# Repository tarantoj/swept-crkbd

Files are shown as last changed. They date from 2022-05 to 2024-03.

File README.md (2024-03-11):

# Swept Corne
## This board designed is now stable and has reached maintenance mode.

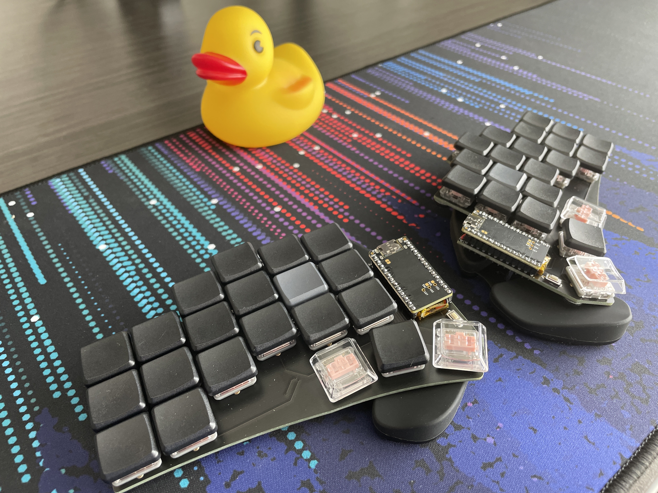
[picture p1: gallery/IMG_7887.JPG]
front of a built swept


back of a built swept

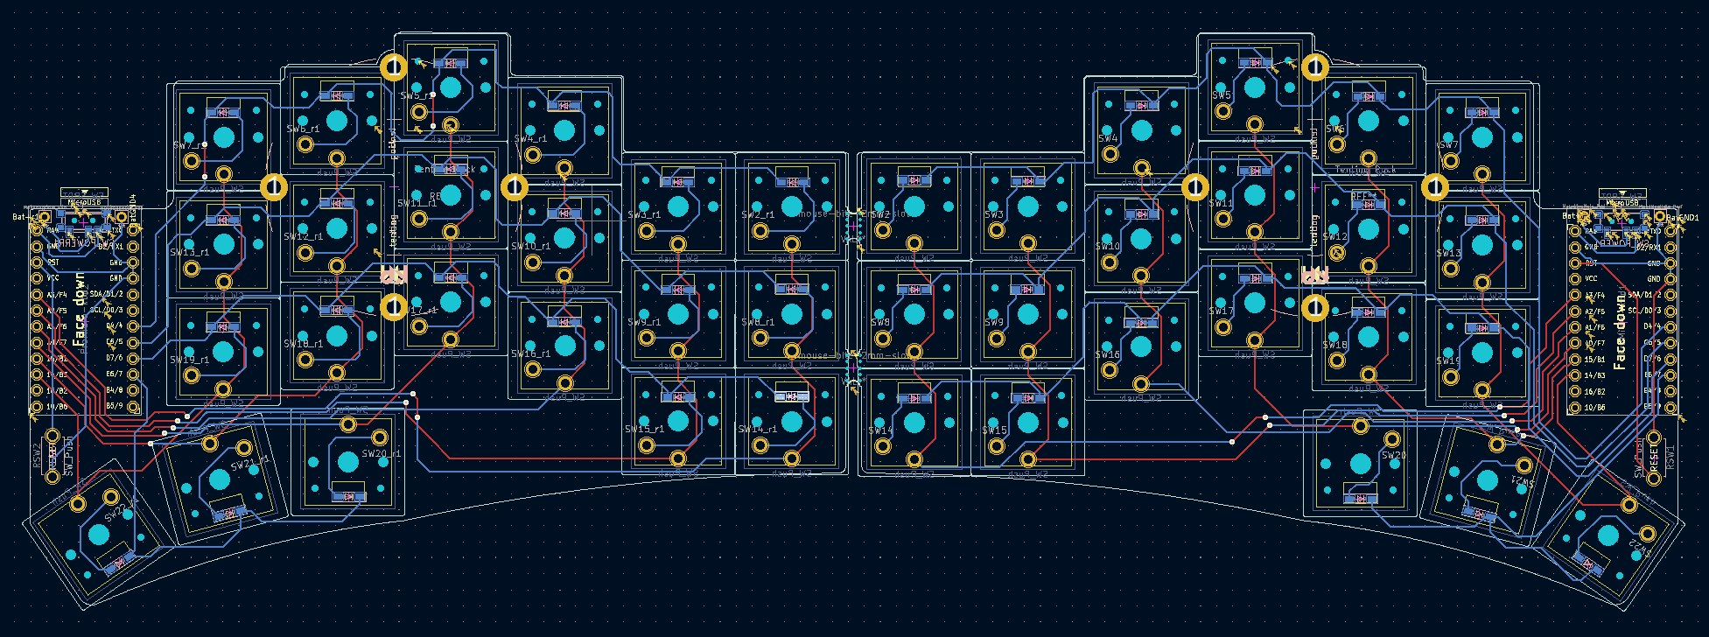
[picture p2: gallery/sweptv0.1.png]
swept v0.1 pcb


## What is the swept corne?

The Swept Corne is a mix between the [Sweep](https://github.com/davidphilipbarr/Sweep) (which is itself a version of the [Ferris](https://github.com/pierrechevalier83/ferris)) and the [Corne](https://github.com/foostan/crkbd).

## Motivation

I made the jump from a 60% qwerty keyboard to colemak mod-dh on a sweep. After getting up to speed both with the new layout and form factor I realized that to reach peak productivity I'd need a few more keys and the corne was the obvious choice but the non-choc spacing,
lack support for a power switch and the less aggresive staggering made me miss the sweep, so I decided to take the sweep as a starting point and add the extra keys by keeping it wireless friendly. The [Corne-is Zen](https://lowprokb.ca/products/corne-ish-zen) has similar
goals but up to this point has only been available through group buys and is closed source.

## What are the different types?

There's currently only one version of the swept with choc spacing as well as an on-off switch and no TRRS connector, this is to have the reset switch in a more comfortable position.

## Components list

To build and use a Swept you will need

* 1x PCB Kit (Instructions on how to order below).
* 2 nice!nanos. [Typeractive](https://typeractive.xyz/) has good prices, as well as fast shipping and processing.
* 2 batteries. From [Typeractive](https://typeractive.xyz/products/lithium-battery-110mah).
* 2 Mill-Max sockets with pins. Make sure you get the high-profile ones, low-profile still fits a battery underneath but there's less space. [Typeractive](https://typeractive.xyz/products/machine-sockets-and-pins) carries the correct size.
* 42 Choc v1 switches. You can get them from [MKUltra](https://mkultra.click/choc-switches).
* 84 Mill-Max 3305 or 7305 sockets, you can get either model from [prevailkey](https://prevailkeyco.com/products/3305-mill-max-sockets?variant=42568596193534). These are optional but you can use them to make your board hot-swap. I recommend getting some extra ones because they're very easy to lose.
* 42 smd diodes. From [MKUltra](https://mkultra.click/diode-1n4148-sod-123f/) for flush SOD-123F form factor, or from [Boardsource](https://boardsource.xyz/store/5ec9fc5d64caf04f83aa646c) for glass smd form factor; the former ones might be easier to solder for some people. I recommend getting some extra ones because they're very easy to lose.
* 42 keycaps. You can get them from [MKUltra](https://mkultra.click/mbk-choc-keycaps) or [Boardsource](https://boardsource.xyz/store/5f6ef2d68e3bf05ab838f918). I recommend getting a least a couple of homing keys, available from both providers.
* 2x reset switches ([B3U-1000P(M)](https://github.com/davidphilipbarr/Sweep/issues/20)). [This kit](https://www.amazon.com/dp/B07LCBLB8N?psc=1&ref=ppx_yo2ov_dt_b_product_details) includes switches that fit.
* Rubber feet, [these](https://www.amazon.com/dp/B07CNQC695?psc=1&ref=ppx_yo2ov_dt_b_product_details) work great.
* 2x power switches. [these](https://www.amazon.com/Gikfun-Switch-Toggle-Arduino-AE1073/dp/B01GFFGA4I/ref=psdc_495324_t1_B07SJWWYZP) work great.
* 1 USB C cable.

Note: All purchase links are for the US, PRs with links for other countries are welcome.

## Ordering The PCB

To order the PCB the following settings are recommended: 

|Detail|Value|
|---|---|
|Gerber file|`Swept_Y_vX.zip` where Y stands for variation and X stands for version|
|Base material|FR-4|
|Layers|2|
|Dimension| Depends on the board, this is picked up automatically by JLCPCB|
|Different design|2|
|Delivery format|Panel by customer|
|PCB thickness|1.6mm|
|PCB color|(Personal preference)|
|Silkscreen|(Personal preference)|
|Surface finish|(Personal preference)|
|Outer copper weight|1oz|
|Gold Fingers|No|
|Confirm production file|No|
|Castellated holes|No|
|Remove order number|Yes|

Find the different versions on the releases page.

1: Settings are for [JLCPCB](https://jlcpcb.com/), but could work for other manufacturers.

2: Settings are taken from [Kyek's video guide](https://www.youtube.com/watch?v=fBPu7AyDtkM&t=17s).

## How do I make this thing?

Build video coming soon.

## What if I want one but I don't want to build it?

Visit [my Etsy shop](https://www.etsy.com/listing/1235225784/custom-swept-corne-split-wireless) to get one built by me.

## Firmware

Firmware for zmk and nice!nano is called ["Corne"](https://zmk.dev/docs/hardware/).

[My personal configuration](https://github.com/AYM1607/corne-zmk-config). Tested on the v0.1 version.

## Changelog

### v1.1.1 (Recommended version)

- Added extra mountig holes for ease of case design.

### v1.1.0 

- Added support for the [nice!view](https://nicekeyboards.com/nice-view) sharp memory displays. You don't need it to build a keyboard, it's completely optional.

### v1.0.0 

- Boards now have optional support for Kailh choc hot-swap sockets.
- The form factor is not exactly the same to accomodate the sockets.

### v0.2.0

- Introduced the Swept Corne 3x5
- All the diodes now face the same way on both boards.

### v0.1.2 

- Updated silk screen to make the battery polarity easier to read.

### v0.1.1

- Deleted extra holes from the switch footprint which might be causing manufacturers to charge extra.

### v0.1

Differences from the original Sweep:
- Added an extra pinky column.
- Added an extra thumb key.
- Converted from direct to switch connections to matrix with diodes keeping compatibility with the corne.

The following versioning schema will be followed as closely as possible.
- Major versions: Changes to the form factor.
- Minor versions: Changes that affect the build processs, e.g. Position or orientation of components.
- Patch versions: No change to the build process.

## Who made this?

* [AYM1607](https://github.com/AYM1607)

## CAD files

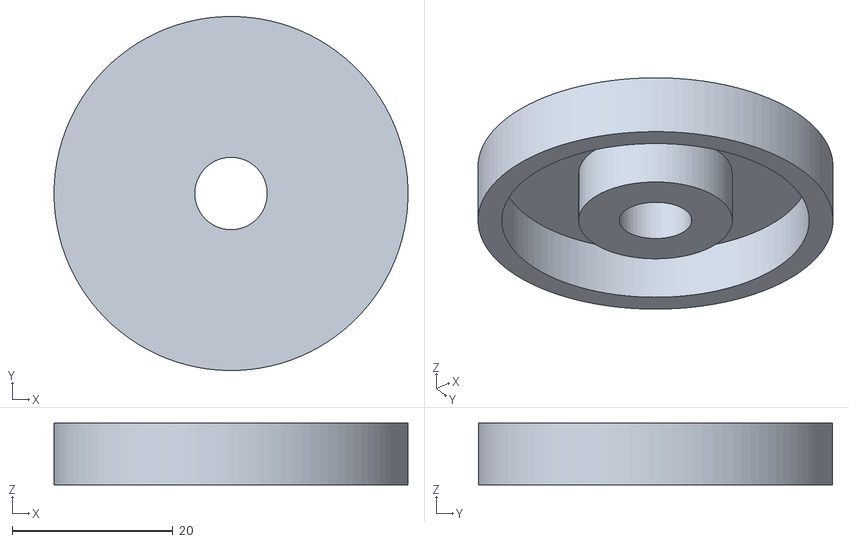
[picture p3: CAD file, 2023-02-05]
cases/Puck.stl
44.0 x 44.0 x 7.70

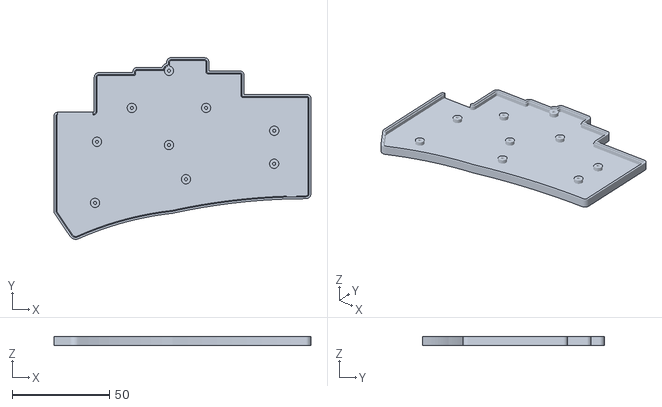
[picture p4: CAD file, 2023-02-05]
cases/v1.1.1/3x6_right_slim.stl
131.8 x 93.2 x 4.50

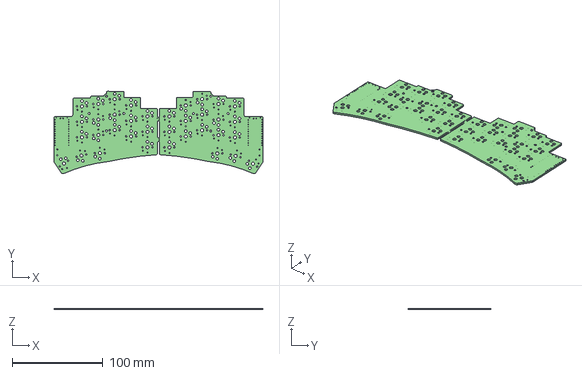
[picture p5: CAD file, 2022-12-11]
Swept_3x5/Swept_3x5.step
229.8 x 90.7 x 1.60 mm

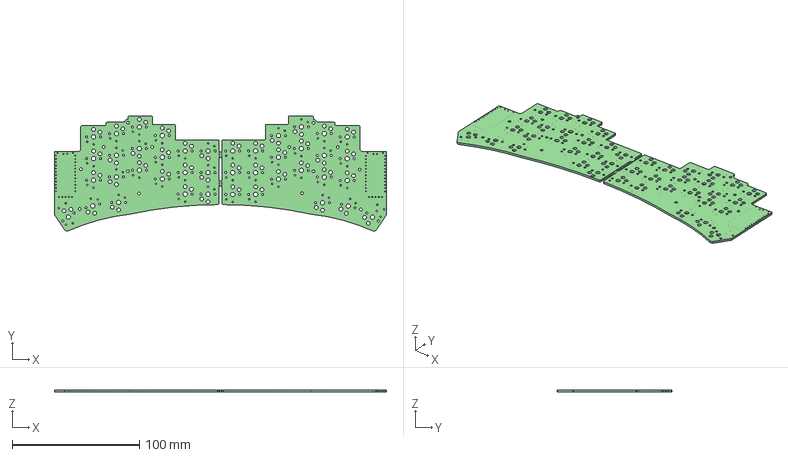
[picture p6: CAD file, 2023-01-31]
Swept_3x6/Swept_3x6.step
261.1 x 90.7 x 1.60 mm

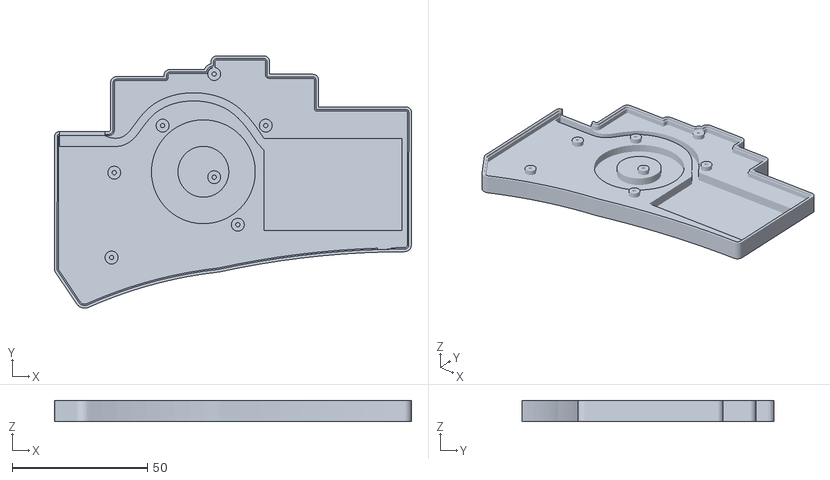
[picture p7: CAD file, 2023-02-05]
cases/v1.1.1/3x6_right.stl
131.8 x 93.2 x 7.80

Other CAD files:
cases/v1.1.1/3x6_left_slim.stl
cases/v1.1.1/3x6_left.stl
cases/v1.0.0/3x6_left.stl
cases/v1.1.0/3x6_left.stl
cases/v1.1.0/3x6_left_slim.stl
cases/v1.0.0/3x6_left_slim.stl

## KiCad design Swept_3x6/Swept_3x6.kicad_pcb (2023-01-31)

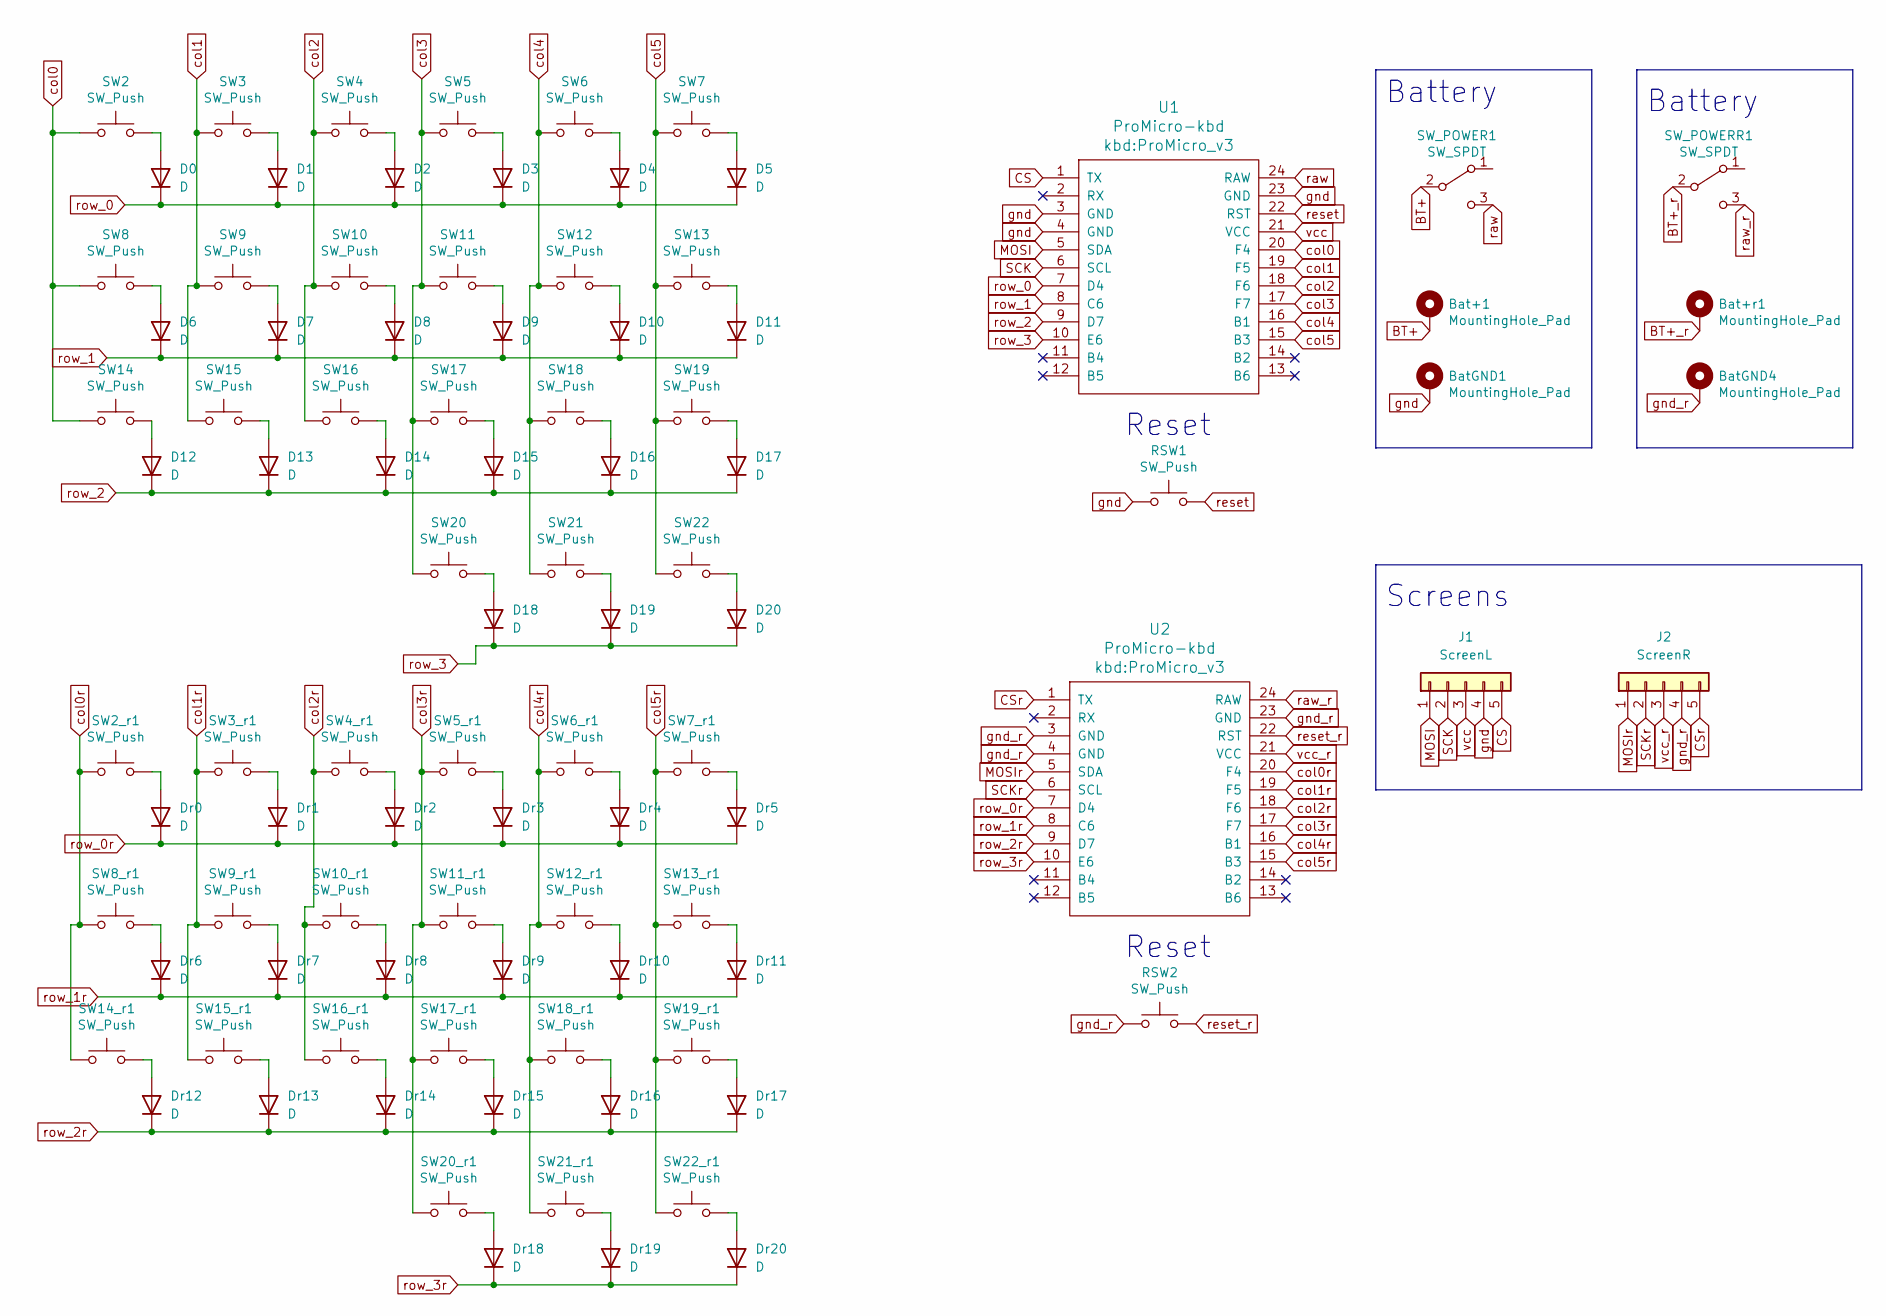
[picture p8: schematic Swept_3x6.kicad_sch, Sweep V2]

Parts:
Bat+1: MountingHole_Pad; 1pin_conn
Bat+r1: MountingHole_Pad; 1pin_conn
BatGND1, BatGND4: MountingHole_Pad; 1pin_conn
D0, D1, D2, D3, D4, D5, D6, D7, D8, D9, D10, D11, D12, D13, D14, D15, D16, D17, D18, D19, D20: D; D3_SMD_v2; LCSC C2099
Dr0, Dr1, Dr2, Dr3, Dr4, Dr5, Dr6, Dr7, Dr8, Dr9, Dr10, Dr11, Dr12, Dr13, Dr14, Dr15, Dr16, Dr17, Dr18, Dr19, Dr20: D; D3_SMD_v2; LCSC C2099
J1: ScreenL; PinHeader_1x05_P2.54mm_Vertical
J2: ScreenR; PinHeader_1x05_P2.54mm_Vertical
RSW1, RSW2: SW_Push; ResetSW
SW2, SW2_r1, SW3, SW3_r1, SW4, SW4_r1, SW5, SW5_r1, SW6, SW6_r1, SW7, SW7_r1, SW8, SW8_r1, SW9, SW9_r1, SW10, SW10_r1, SW11, SW11_r1, SW12, SW12_r1, SW13, SW13_r1, SW14, SW14_r1, SW15, SW15_r1, SW16, SW16_r1, SW17, SW17_r1, SW18, SW18_r1, SW19, SW19_r1, SW20, SW20_r1, SW21, SW21_r1, SW22, SW22_r1: SW_Push; Kailh_socket_PG1350_optional
SW_POWER1: SW_SPDT; SW_SPDT_PCM12
SW_POWERR1: SW_SPDT; SW_SPDT_PCM12
U1, U2: ProMicro-kbd; ProMicro_v3

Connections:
BT+: Bat+1.1, SW_POWER1.2 (B)
BT+_r: Bat+r1.1, SW_POWERR1.2 (B)
CS: J1.5, U1.1 (TX)
CSr: J2.5, U2.1 (TX)
MOSI: J1.1, U1.5 (SDA)
MOSIr: J2.1, U2.5 (SDA)
unnamed: D0.2 (A), SW2.2
unnamed: D1.2 (A), SW3.2
unnamed: D2.2 (A), SW4.2
unnamed: D3.2 (A), SW5.2
unnamed: D4.2 (A), SW6.2
unnamed: D5.2 (A), SW7.2
unnamed: D6.2 (A), SW8.2
unnamed: D7.2 (A), SW9.2
unnamed: D8.2 (A), SW10.2
unnamed: D9.2 (A), SW11.2
unnamed: D10.2 (A), SW12.2
unnamed: D11.2 (A), SW13.2
unnamed: D12.2 (A), SW14.2
unnamed: D13.2 (A), SW15.2
unnamed: D14.2 (A), SW16.2
unnamed: D15.2 (A), SW17.2
unnamed: D16.2 (A), SW18.2
unnamed: D17.2 (A), SW19.2
unnamed: D18.2 (A), SW20.2
unnamed: D19.2 (A), SW21.2
unnamed: D20.2 (A), SW22.2
unnamed: Dr0.2 (A), SW2_r1.2
unnamed: Dr1.2 (A), SW3_r1.2
unnamed: Dr2.2 (A), SW4_r1.2
unnamed: Dr3.2 (A), SW5_r1.2
unnamed: Dr4.2 (A), SW6_r1.2
unnamed: Dr5.2 (A), SW7_r1.2
unnamed: Dr6.2 (A), SW8_r1.2
unnamed: Dr7.2 (A), SW9_r1.2
unnamed: Dr8.2 (A), SW10_r1.2
unnamed: Dr9.2 (A), SW11_r1.2
unnamed: Dr10.2 (A), SW12_r1.2
unnamed: Dr11.2 (A), SW13_r1.2
unnamed: Dr12.2 (A), SW14_r1.2
unnamed: Dr13.2 (A), SW15_r1.2
unnamed: Dr14.2 (A), SW16_r1.2
unnamed: Dr15.2 (A), SW17_r1.2
unnamed: Dr16.2 (A), SW18_r1.2
unnamed: Dr17.2 (A), SW19_r1.2
unnamed: Dr18.2 (A), SW20_r1.2
unnamed: Dr19.2 (A), SW21_r1.2
unnamed: Dr20.2 (A), SW22_r1.2
SCK: J1.2, U1.6 (SCL)
SCKr: J2.2, U2.6 (SCL)
col0: SW2.1, SW8.1, SW14.1, U1.20 (F4)
col0r: SW2_r1.1, SW8_r1.1, SW14_r1.1, U2.20 (F4)
col1: SW3.1, SW9.1, SW15.1, U1.19 (F5)
col1r: SW3_r1.1, SW9_r1.1, SW15_r1.1, U2.19 (F5)
col2: SW4.1, SW10.1, SW16.1, U1.18 (F6)
col2r: SW4_r1.1, SW10_r1.1, SW16_r1.1, U2.18 (F6)
col3: SW5.1, SW11.1, SW17.1, SW20.1, U1.17 (F7)
col3r: SW5_r1.1, SW11_r1.1, SW17_r1.1, SW20_r1.1, U2.17 (F7)
col4: SW6.1, SW12.1, SW18.1, SW21.1, U1.16 (B1)
col4r: SW6_r1.1, SW12_r1.1, SW18_r1.1, SW21_r1.1, U2.16 (B1)
col5: SW7.1, SW13.1, SW19.1, SW22.1, U1.15 (B3)
col5r: SW7_r1.1, SW13_r1.1, SW19_r1.1, SW22_r1.1, U2.15 (B3)
gnd: BatGND1.1, J1.4, RSW1.1, U1.3 (GND), U1.4 (GND), U1.23 (GND)
gnd_r: BatGND4.1, J2.4, RSW2.1, U2.3 (GND), U2.4 (GND), U2.23 (GND)
raw: SW_POWER1.3 (C), U1.24 (RAW)
raw_r: SW_POWERR1.3 (C), U2.24 (RAW)
reset: RSW1.2, U1.22 (RST)
reset_r: RSW2.2, U2.22 (RST)
row_0: D0.1 (K), D1.1 (K), D2.1 (K), D3.1 (K), D4.1 (K), D5.1 (K), U1.7 (D4)
row_0r: Dr0.1 (K), Dr1.1 (K), Dr2.1 (K), Dr3.1 (K), Dr4.1 (K), Dr5.1 (K), U2.7 (D4)
row_1: D6.1 (K), D7.1 (K), D8.1 (K), D9.1 (K), D10.1 (K), D11.1 (K), U1.8 (C6)
row_1r: Dr6.1 (K), Dr7.1 (K), Dr8.1 (K), Dr9.1 (K), Dr10.1 (K), Dr11.1 (K), U2.8 (C6)
row_2: D12.1 (K), D13.1 (K), D14.1 (K), D15.1 (K), D16.1 (K), D17.1 (K), U1.9 (D7)
row_2r: Dr12.1 (K), Dr13.1 (K), Dr14.1 (K), Dr15.1 (K), Dr16.1 (K), Dr17.1 (K), U2.9 (D7)
row_3: D18.1 (K), D19.1 (K), D20.1 (K), U1.10 (E6)
row_3r: Dr18.1 (K), Dr19.1 (K), Dr20.1 (K), U2.10 (E6)
vcc: J1.3, U1.21 (VCC)
vcc_r: J2.3, U2.21 (VCC)

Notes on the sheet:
Reset
Battery
Screens

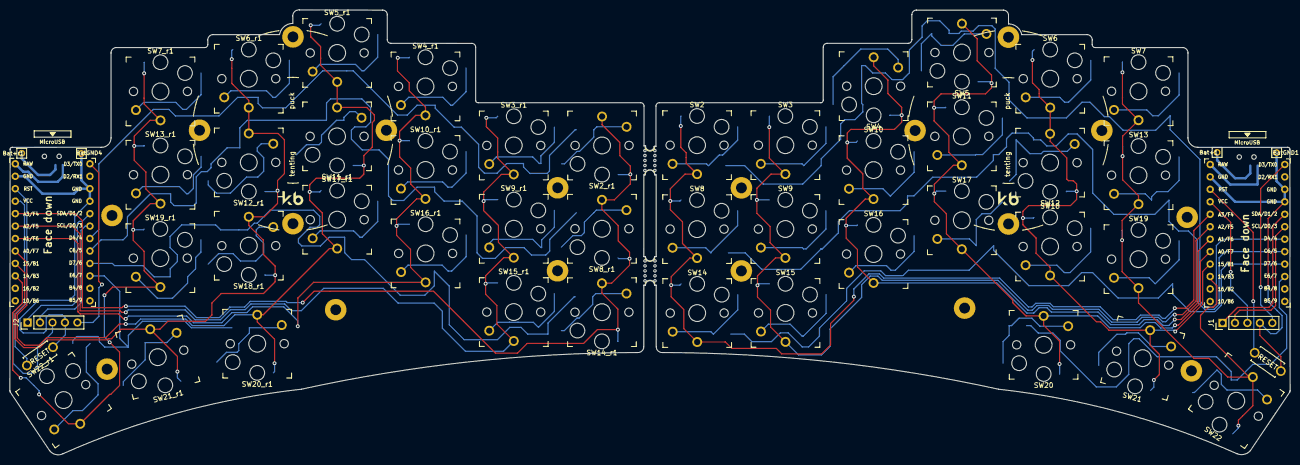
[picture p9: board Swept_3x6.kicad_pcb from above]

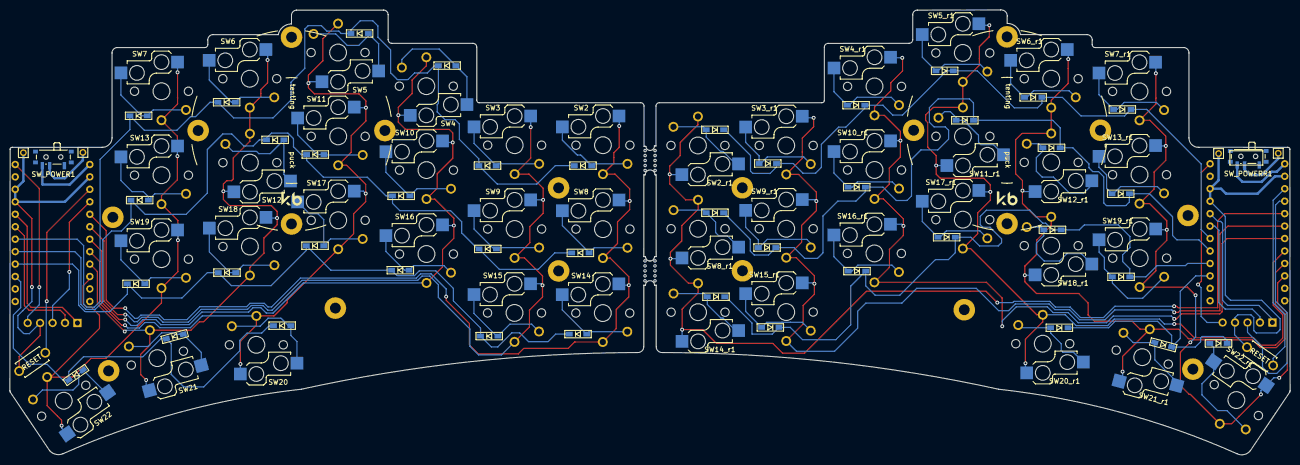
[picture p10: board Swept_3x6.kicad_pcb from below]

Board: 2 copper layers, 261.1 x 90.7 mm, 98 parts (44 on the bottom side), 78 nets.

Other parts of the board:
mouse-bite-2mm-slot, mouse-bite-2mm-slot#2: VAL**; mouse-bite-5mm-slot-with-space-for-track

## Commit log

2022-05-29 Schematic finished, pcb ready to route.
    [sweepv2.kicad_pcb, sweepv2.kicad_sch]
2022-05-30 Done with routing.
    [sweepv2.kicad_pcb, sweepv2.kicad_sch]
2022-05-30 Generated gerber and zip.
    [sweepv2-B_Cu.gbr, sweepv2-B_Mask.gbr, sweepv2-B_Silkscreen.gbr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]
2022-05-30 Update readme and moved gerber zip to root.
2022-06-04 Deleted extra unused holes from the switch footrprint.
    [sweepv2.kicad_pcb]
2022-06-20 Add footprint lib to the repo
2022-06-20 Create version 0.1.2
    [sweepv2-B_Cu.gbr, sweepv2-B_Mask.gbr, sweepv2-B_Silkscreen.gbr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]
2022-06-23 Version 0.2.0
    [Swept_3x5-B_Cu.gbr, Swept_3x5-B_Mask.gbr, Swept_3x5-B_Silkscreen.gbr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]
2022-07-05 Added support for Kailh hot-swap sockets.
    [Swept_3x5-B_Cu.gbr, Swept_3x5-B_Mask.gbr, Swept_3x5-B_Silkscreen.gbr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]
2022-07-10 Added footprint for MS88SF31
2022-12-11 Added nice!view suppor for 3x6
    [Swept_3x5.step, Swept_3x6.kicad_pcb, Swept_3x6.kicad_sch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]
2022-12-12 Added nice!view support for 3x5
    [Swept_3x5.kicad_pcb, Swept_3x5.kicad_sch, Swept_3x6.kicad_sch]
2023-01-31 Version 1.1.1 of the 3x6 swept.
    [Swept_3x6-B_Cu.gbr, Swept_3x6-B_Mask.gbr, Swept_3x6-B_Silkscreen.gbr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]
2023-02-05 Cases up to v1.1.1
    [3x6_left.stl, 3x6_left_slim.stl, 3x6_right.stl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]
